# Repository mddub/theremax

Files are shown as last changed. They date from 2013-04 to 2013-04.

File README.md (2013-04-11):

# theremax

A theremin-like instrument for Arduino, using a HC-SR04 ultrasonic ranging module.

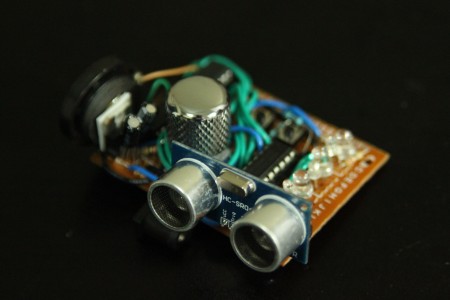
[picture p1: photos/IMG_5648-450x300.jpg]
Theremax


## Demo

* [Demo video](http://youtu.be/Jf77zi0XjPk)

## Features

* Play notes of a C major scale based on distance from instrument
* 6 octaves, adjustable by rotary encoder
* Sharp button (modulate up half a step)
* Loop recording mode with metronome light and tempo adjustable by rotary encoder

## Requirements

### Hardware

* Arduino Uno
* HC-SR04 ultrasonic ranging module
* Speaker/buzzer
* Rotary encoder with built-in push button
* 74HC595 shift register
* 9 LEDs
* 2 push buttons

See the included Fritzing diagram for details (+ wires, resistors, etc.).

### Arduino Libraries

* [NewPing][1] (for ultrasonic sensor)
* [Tone][2] (for speaker)

## TODO/Wishlist
* Fix some intermittent tempo issues during loop playback
* Indicator of current recording bar on LEDs (using [ShiftPWM][3])
* Record/playback two tones at once ([Tone][2] supports this)

## Etc.

* [A time-lapse video of us prototyping and building this](http://youtu.be/0IkWHqgWssk)

[1]: http://playground.arduino.cc/Code/NewPing
[2]: https://code.google.com/p/rogue-code/wiki/ToneLibraryDocumentation
[3]: http://www.elcojacobs.com/shiftpwm/

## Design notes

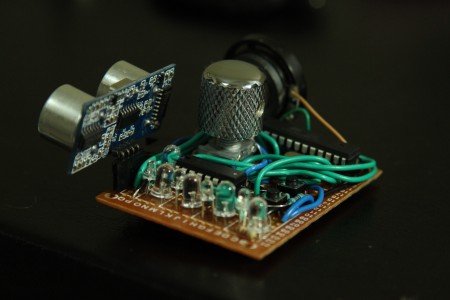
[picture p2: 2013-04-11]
photos/IMG_5660-450x300.jpg

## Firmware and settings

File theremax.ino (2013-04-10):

/*
Theremax, a theremin-like instrument for Arduino.

Some resources which were helpful:
http://www.instructables.com/id/Simple-Arduino-and-HC-SR04-Example/step3/Upload-the-sketch/
http://playground.arduino.cc/Code/NewPing
https://code.google.com/p/rogue-code/wiki/ToneLibraryDocumentation
*/

#include <NewPing.h>
#include <Tone.h>

///////////////////////////////////
// constants

#define trigPin 3
#define echoPin 4
#define speakerPin1 9
//#define speakerPin2 10
#define buttonPin 6
#define rotaryPin1 0
#define rotaryPin2 1
#define sharpPin 7
#define modePin 2
#define metronomeLightPin 5

//Pin connected to ST_CP of 74HC595
int latchPin = 8;
//Pin connected to SH_CP of 74HC595
int clockPin = 12;
////Pin connected to DS of 74HC595
int dataPin = 11;

const int NUM_OCTAVES = 6;
double scales[NUM_OCTAVES][8] = {
  {65, 73, 82, 87, 98, 110, 123, 131},
  {NOTE_C3, NOTE_D3, NOTE_E3, NOTE_F3, NOTE_G3, NOTE_A3, NOTE_B3, NOTE_C4},
  {NOTE_C4, NOTE_D4, NOTE_E4, NOTE_F4, NOTE_G4, NOTE_A4, NOTE_B4, NOTE_C5},
  {NOTE_C5, NOTE_D5, NOTE_E5, NOTE_F5, NOTE_G5, NOTE_A5, NOTE_B5, NOTE_C6},
  {NOTE_C6, NOTE_D6, NOTE_E6, NOTE_F6, NOTE_G6, NOTE_A6, NOTE_B6, NOTE_C7},
  {NOTE_C7, NOTE_D7, NOTE_E7, NOTE_F7, NOTE_G7, NOTE_A7, NOTE_B7, NOTE_C8}
};

double HALF_STEP_RATIO = 1.059463094359;

#define MAX_SENSOR_DISTANCE 200 // Maximum distance we want to ping for (in centimeters). Maximum sensor distance is rated at 400-500cm.

const int MODE_BUTTON_CHECK_FREQUENCY = 20; // ms
const int BUTTON_HOLD_MIN_LENGTH = 25;

///////////////////////////////////
// globals

NewPing sonar(trigPin, echoPin, MAX_SENSOR_DISTANCE); // NewPing setup of pins and maximum distance.

Tone notePlayer[2];

long currentDistance = 0;

double distanceCheckTimer[1] = {0};
double playButtonCheckTimer[1] = {0};
double sharpCheckTimer[1] = {0};
double loopTimer[1] = {0};

int playButtonPressed = 0;
boolean playing = false;
int playingTone;

int currentDistanceIndex;
int sharpPressed = 0;

boolean metronomeOn = false;

const boolean MODE_FREESTYLE = true;
const boolean MODE_LOOP = false;
boolean mode = MODE_FREESTYLE;

const boolean ROTARY_TEMPO = true;
const boolean ROTARY_OCTAVE = false;
boolean rotaryMode = ROTARY_OCTAVE;

int currentOctave = 1;

const int BUTTON_NO_CLICK = 0;
const int BUTTON_CLICKED = 1;
const int BUTTON_LONG_CLICKED = 2;

#define NUM_SAMPLES_PER_NOTE 16
#define MAX_NOTES 128
#define MIN_TEMPO 8
#define MAX_TEMPO 250
int currentTempo = 50; // length of eighth note, in ms

double samples[NUM_SAMPLES_PER_NOTE];
double currentSong[MAX_NOTES];

int currentSampleIndex = 0;
int currentLoopPosition = 0;

///////////////////////////////////

void setup() {
  pinMode(trigPin, OUTPUT);
  pinMode(echoPin, INPUT);
  pinMode(buttonPin, INPUT);
  pinMode(sharpPin, INPUT);
  pinMode(modePin, INPUT);
  pinMode(rotaryPin1, INPUT);
  pinMode(rotaryPin2, INPUT);
  pinMode(latchPin, OUTPUT);
  pinMode(clockPin, OUTPUT);
  pinMode(dataPin, OUTPUT);
  pinMode(metronomeLightPin, OUTPUT);

  notePlayer[0].begin(speakerPin1);
  //notePlayer[1].begin(speakerPin2);

  for(int i = 0; i < MAX_NOTES; i++) {
    currentSong[i] = -1;
  }
}

void loop() {
  boolean playButtonChanged = updatePlayButtonState();
  boolean sharpButtonChanged = updateSharpButtonState();
  boolean distanceIndexChanged = updateCurrentDistanceIndex();

  boolean loopChanged = updateLoopPosition();

  int modeButtonState = getModeButtonState();

  bool modeChanged = false;
  if(modeButtonState == BUTTON_LONG_CLICKED) {
    modeChanged = true;
    // switch instrument mode (freestyle vs loop)
    mode = (mode == MODE_FREESTYLE ? MODE_LOOP : MODE_FREESTYLE);
    if(mode == MODE_FREESTYLE) {
      rotaryMode = ROTARY_OCTAVE;
    }
  }
  else if(mode == MODE_LOOP && modeButtonState == BUTTON_CLICKED) {
    // in loop mode, switch rotary mode (change tempo vs change octave)
    rotaryMode = (rotaryMode == ROTARY_OCTAVE ? ROTARY_TEMPO : ROTARY_OCTAVE);
  }

  if(mode == MODE_LOOP) {
    tickMetronomeLight();
  }
  else {
    disableMetronomeLight();
  }

  boolean octaveChanged = updateTempoOrOctave();

  if(distanceIndexChanged) {
    updateHighlightedTone(currentDistanceIndex);
  }

  if(mode == MODE_FREESTYLE) {
    if(distanceIndexChanged || playButtonChanged || sharpButtonChanged || modeChanged || octaveChanged) {
      // this is kind of gross. this is all the changes that should prompt us
      // to reconsider the tone we're emitting now based on user input
      updatePlayingToneFromEnvironment();
    }
  }
  else if(mode == MODE_LOOP) {
    if(distanceIndexChanged || playButtonChanged || sharpButtonChanged || loopChanged || octaveChanged) {
      // similarly, any change that might cause us to change what note we're
      // playing based on recorded tones + user input
      updateRecordingTone(playButtonChanged, loopChanged);
    }
  }
}

///////////////////////////////////

boolean updatePlayButtonState() {
  if(tick(11, playButtonCheckTimer)) {
    int oldButton = playButtonPressed;
    playButtonPressed = digitalRead(buttonPin);
    return oldButton != playButtonPressed;
  }
  return false;
}

boolean updateSharpButtonState() {
  if(tick(11, sharpCheckTimer)) {
    int oldSharp = sharpPressed;
    sharpPressed = digitalRead(sharpPin);
    return oldSharp != sharpPressed;
  }
  return false;
}

boolean updateCurrentDistanceIndex() {
  if(tick(40, distanceCheckTimer)) {
    updateDistance();
    int oldDistanceIndex = currentDistanceIndex;
    updateIndexFromDistance(currentDistance);
    return oldDistanceIndex != currentDistanceIndex;
  }
  return false;
}

void updateHighlightedTone(int distanceIndex) {
  if(distanceIndex >= 0) {
    noteLightOn(distanceIndex);
  }
  else if(distanceIndex < 0) {
    noteLightOff();
  }
}

void updatePlayingToneFromEnvironment() {
  int newTone;
  if(currentDistanceIndex == -1 || !playButtonPressed) {
    newTone = -1;
  }
  else if(currentDistanceIndex >= 0) {
    newTone = currentDistanceIndex >= 0 ? scales[currentOctave][currentDistanceIndex] : currentDistanceIndex;
    if(sharpPressed) {
      newTone = (int)((double)newTone * HALF_STEP_RATIO);
    }
  }
  playTone(newTone);
}

void playTone(int newTone) {
  if(newTone >= 0 && (!playing || newTone != playingTone)) {
    notePlayer[0].play(newTone);
    playing = true;
    playingTone = newTone;
  }
  else if(newTone < 0 && playing) {
    notePlayer[0].stop();
    playing = false;
  }
}

boolean updateLoopPosition() {
  int sampleFreq = currentTempo / NUM_SAMPLES_PER_NOTE;
  if(tick(sampleFreq, loopTimer)) {
    currentSampleIndex++;
    if(currentSampleIndex == NUM_SAMPLES_PER_NOTE) {
      currentSampleIndex = 0;
      currentLoopPosition = (currentLoopPosition + 1) % MAX_NOTES;
    }
    return true;
  }
  return false;
}

void updateRecordingTone(boolean playButtonChanged, boolean loopChanged) {
  if(!playButtonPressed) {
    if(loopChanged) {
      int newTone = currentSong[currentLoopPosition];
      playTone(newTone);
    }
  }
  else {
    updatePlayingToneFromEnvironment();
    updateRecordedNote();
  }
}

void updateRecordedNote() {
  samples[currentSampleIndex] = playing ? playingTone : -1;
  if(currentSampleIndex == 0) {
    // need to decide what to save for previous note
    int previousNoteIndex = (currentLoopPosition - 1) % MAX_NOTES;
    currentSong[previousNoteIndex] = determineSampledNoteValue();
  }
}

int determineSampledNoteValue() {
  // do a really dumb O(n^2) search through the array to
  // find the first value with >= 50% representation.
  int minSamples = NUM_SAMPLES_PER_NOTE / 2;

  for(int i = 0; i < NUM_SAMPLES_PER_NOTE; i++) {
    int candidateValue = samples[i];
	int count = 0;
	for(int j = 0; j < NUM_SAMPLES_PER_NOTE; j++) {
	  if(abs(candidateValue - samples[j]) < 0.001) {
	    count++;
	  }
	}
	if(count >= minSamples) {
	  return candidateValue;
	}
  }

  // if no candidate, record silence.
  return -1;
}

void tickMetronomeLight() {
  int currentNote = currentLoopPosition / 8;
  boolean metronomeState = currentNote % 2;
  if(metronomeState != metronomeOn) {
    metronomeOn = !metronomeOn;
    // if we are in tempo-set mode, make the metronome dim
    // instead of completely off
    int lowValue = (rotaryMode == ROTARY_TEMPO ? 40 : 0);
    analogWrite(metronomeLightPin, metronomeOn ? 255 : lowValue);
  }
}

void disableMetronomeLight() {
  metronomeOn = false;
  analogWrite(metronomeLightPin, 0);
}

///////////////////////////////////
// mostly copy-pasted

unsigned char encoder_A_prev;

boolean updateTempoOrOctave() {
  int delta = 0;

  unsigned char encoder_A = digitalRead(rotaryPin1);
  unsigned char encoder_B = digitalRead(rotaryPin2);
  if((!encoder_A) && (encoder_A_prev)){
    // A has gone from high to low
    if(encoder_B) {
      // B is high so clockwise
      delta = 1;
    }
    else {
      // B is low so counter-clockwise
      delta = -1;
    }
  }
  encoder_A_prev = encoder_A;

  if(delta != 0) {
    if(rotaryMode == ROTARY_OCTAVE) {
      int newOctave = currentOctave + delta;
      if(newOctave >= 0 && newOctave < NUM_OCTAVES) {
        currentOctave = newOctave;
        return true;
      }
    }
    else if(rotaryMode == ROTARY_TEMPO) {
      // make size of tempo change proportional to current tempo
      int tempoDelta = (int)(-4.0 * (double)currentTempo / 30.0 * (double)delta);
      tempoDelta = 0 < tempoDelta && tempoDelta < 2 ? 2 : tempoDelta;
      tempoDelta = 0 > tempoDelta && tempoDelta > -2 ? -2 : tempoDelta;
      int newTempo = currentTempo + tempoDelta;
      newTempo = newTempo < MIN_TEMPO ? MIN_TEMPO : newTempo;
      newTempo = newTempo > MAX_TEMPO ? MAX_TEMPO : newTempo;
      currentTempo = newTempo;
    }
  }

  return false;
}

///////////////////////////////////
// determine state of mode change button

double modeButtonTimer[1] = {0};
boolean triggeredDoubleClick = false;
int clickLength = 0;

int getModeButtonState() {
  if(tick(MODE_BUTTON_CHECK_FREQUENCY, modeButtonTimer)) {
    int button_pushed = digitalRead(modePin);
    if(button_pushed) {
      clickLength++;
      if(clickLength == BUTTON_HOLD_MIN_LENGTH) {
        if(!triggeredDoubleClick) {
          triggeredDoubleClick = true;
          return BUTTON_LONG_CLICKED;
        }
      }
    }
    else if(!button_pushed) {
      if(clickLength > 0) {
        clickLength = 0;
        if(!triggeredDoubleClick) {
          return BUTTON_CLICKED;
        }
      }
      triggeredDoubleClick = false;
    }
  }
  return BUTTON_NO_CLICK;
}

///////////////////////////////////
// distance to index, with debouncing of out-of-range notes and note changes

const int MIN_DISTANCE = 300;
const int NUM_NOTES = 8; // c major for now
const double NOTE_WIDTH = 300.0;
const double NOTE_BOUNDARY_WIDTH = 50;
double MAX_DISTANCE = MIN_DISTANCE + NUM_NOTES * NOTE_WIDTH;

int consecutiveOutOfRange = 0;
const int OUT_OF_RANGE_THRESHOLD = 8;

int consecutiveChangedNote = 0;
const int NOTE_CHANGE_THRESHOLD = 9999;

void updateIndexFromDistance(unsigned int distance) {
  if(distance < MIN_DISTANCE || distance > MAX_DISTANCE) {
    if(++consecutiveOutOfRange > OUT_OF_RANGE_THRESHOLD) {
      currentDistanceIndex = -1;
    }
    return;
  }
  else {
    consecutiveOutOfRange = 0;
  }

  int index = (distance - MIN_DISTANCE) / NOTE_WIDTH;
  index = index % NUM_NOTES;

  // there is a segment at either edge of each note which must be debounced before it is accepted as a note change
  if(distance < MIN_DISTANCE + index * NOTE_WIDTH + NOTE_BOUNDARY_WIDTH || distance > MIN_DISTANCE + (index + 1) * NOTE_WIDTH - NOTE_BOUNDARY_WIDTH) {
    if(index != currentDistanceIndex) {
      if(++consecutiveChangedNote >= NOTE_CHANGE_THRESHOLD) {
        currentDistanceIndex = index;
      }
    }
  }
  else {
    consecutiveChangedNote = 0;
    currentDistanceIndex = index;
  }
}

///////////////////////////////////

void noteLightOn(int index) {
  index = 7 - index;
  shiftValue(1 << index);
}

void noteLightOff() {
  shiftValue(0);
}

void shiftValue(int value) {
  // take the latchPin low so
  // the LEDs don't change while you're sending in bits:
  digitalWrite(latchPin, LOW);
  // shift out the bits:
  shiftOut(dataPin, clockPin, MSBFIRST, value);
  //take the latch pin high so the LEDs will light up:
  digitalWrite(latchPin, HIGH);
}

void updateDistance() {
  unsigned int uS = sonar.ping(); // Send ping, get ping time in microseconds (uS).
  if(uS) {
    currentDistance = uS;
  }
}

///////////////////////////////////
// below adapted from https://github.com/jerwil/RTC_demo_rotary_alarm

boolean tick(int delay, double timekeeper[1]){
  unsigned long currentTime = millis();
  if(currentTime >= (timekeeper[0] + delay)){
    timekeeper[0] = currentTime;
    return true;
  }
  else {
    return 0;
  }
}

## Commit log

2013-04-07 Initial commit. Just got buzz working with μs delay.
2013-04-08 Control sound on/off with button
2013-04-08 Use LED to indicate current note/distance
2013-04-08 A 'sharp' button to modulate up a half step
2013-04-08 First commit of fritzing file
    Need to add switch and metronome light and wire up buttons and
    ultrasonic sensor
    [Ultrasonic_Instrument.fzz]
2013-04-08 Wired up ultrasonic sensor
    Still need to wire up buttons and add metronome light
    [Ultrasonic_Instrument.fzz]
2013-04-09 Added metronome light and wired buttons
    Waiting to finalize button layout
    [Ultrasonic_Instrument.fzz]
2013-04-09 Straightened lots of the wires, looks better now
    [Ultrasonic_Instrument.fzz]
2013-04-09 No changes, fzz bin still fidd
    [Ultrasonic_Instrument.fzz]
2013-04-09 Fix the ability to record silence; tweak some constants
    [theremax.ino]
2013-04-09 Fix missing high-Cs in scales; DRY up tone-playing code
    [theremax.ino]
2013-04-09 Use short vs long button press instead of single vs double click
    [theremax.ino]
2013-04-10 Use rotary encoder to change tempo or octave
2013-04-10 Change pins and remove serial for deployment to soldered board!
2013-04-10 Fix the ability to record silence
    [theremax.ino]
2013-04-14 Completed circuit diagrams of breadboard & final
    Breadboard wiring is untested and is based on the source code. Not shown
    are 2 22pf capacitors going from legs of 16 MHz crystal to ground on
    soldered circuit.
    [Ultrasonic_Instrument.fzz]
